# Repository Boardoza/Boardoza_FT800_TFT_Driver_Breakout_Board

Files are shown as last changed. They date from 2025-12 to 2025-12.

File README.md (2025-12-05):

# Boardoza FT800 TFT Driver Breakout Board

The **Boardoza FT800 TFT Driver Breakout Board** is a powerful graphics controller solution designed to simplify the creation of high-quality Human-Machine Interfaces (HMIs) for makers and embedded developers. Powered by the **Bridgetek (FTDI) FT800 Embedded Video Engine (EVE)**, this module unburdens your main microcontroller by handling complex graphics rendering, audio processing, and touch control on a dedicated chip. It is the perfect bridge for connecting low-cost MCUs to sophisticated color displays.

Operating with a **5V supply**, the board communicates via a standard **SPI interface** at speeds up to 30 MHz, making it compatible with popular platforms including Arduino, ESP32, STM32, and Raspberry Pi. It supports **WQVGA (480x272)** and **QVGA (320x240)** resolution TFT displays through a standard 40-pin FPC connector. Beyond graphics, it includes a built-in audio engine with PWM output for direct speaker connection. The FT800 offers flexible touch input options with **integrated resistive touch support** and **native capacitive touch connectivity via I²C**, providing a complete multimedia solution for industrial control panels, medical devices, IoT projects, and smart home interfaces.

## [Click here to purchase!](https://www.ozdisan.com/p/arduino-sensorleri-ve-modulleri-613/boardoza-boardoza-ft800-1473939)

|Front Side|Back Side|
|:---:|:---:|
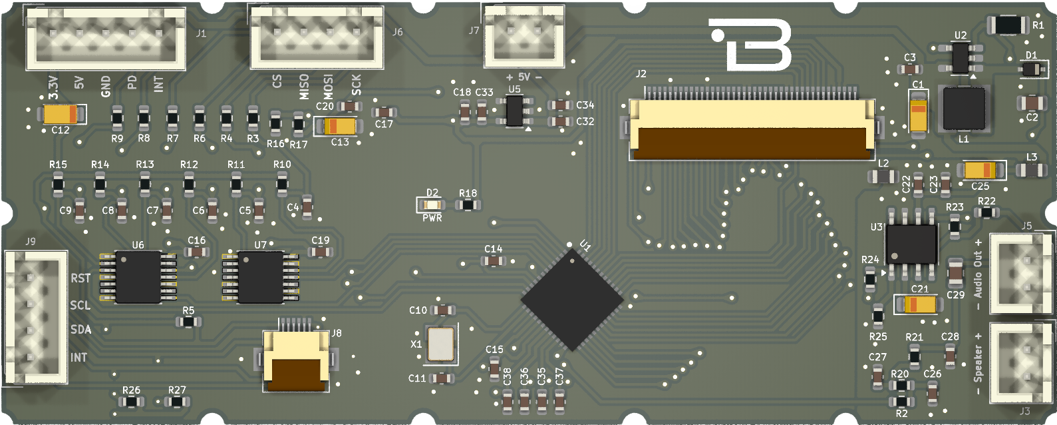
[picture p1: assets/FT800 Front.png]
FT800 Front
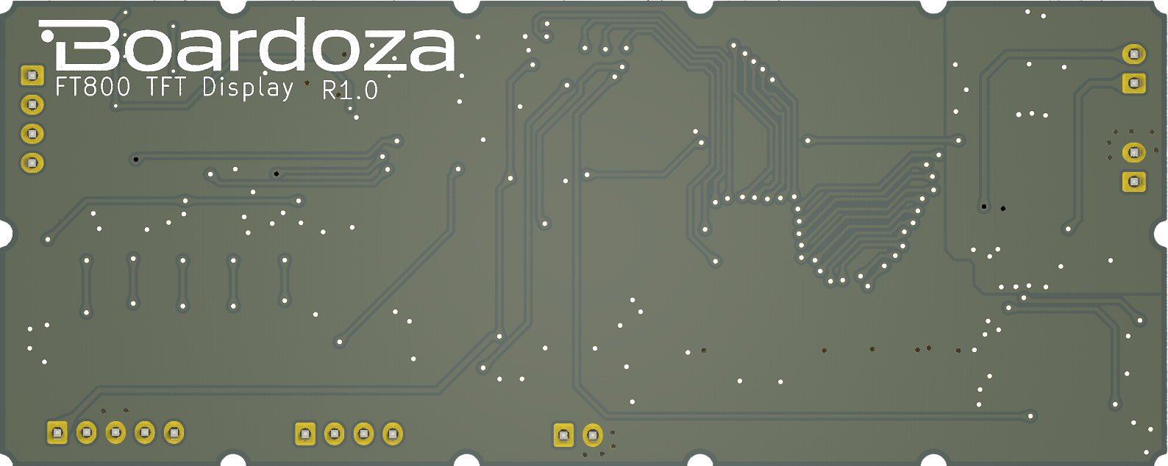
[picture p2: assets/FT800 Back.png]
FT800 Back
| | |

---

## Key Features

- **Dual Resolution Support:** Compatible with WQVGA (480x272) and QVGA (320x240) TFT panels with both DE mode and VSYNC/HSYNC synchronization.  
- **Works with any MCU:** Uses standard SPI, compatible with Arduino, ESP32, STM32, Raspberry Pi Pico, and more.  
- **Resistive & Capacitive Touch Support:** Integrated resistive and capacitive touch controller support via I²C.  
- **Audio Output:** Mono audio channel with PWM output and dedicated speaker connections.  
- **Object-Oriented Architecture:** Advanced command-based system enables low-cost host MCUs to create sophisticated HMI applications.  
- **Perfect for custom HMIs:** Great for dashboards, robotics screens, measurement devices, smart panels, and DIY UI projects.  
- **Display Control Signals:** Built-in display enable, pixel clock, and sync signal outputs for direct TFT panel control.  
- **Interrupt Capability:** Hardware interrupt output for efficient event-driven programming.  

---

## FT800 vs [FT810](https://github.com/Boardoza/Boardoza_FT810_TFT_Driver_Breakout_Board) Comparison

| Feature | FT800 | [FT810](https://github.com/Boardoza/Boardoza_FT810_TFT_Driver_Breakout_Board) |
|:---|:---:|:---:|
| **Supported Resolutions** | WQVGA (480x272), QVGA (320x240) | up to SVGA (800x600) |
| **Maximum Resolution** | WQVGA (480x272) | SVGA (800x600) |
| **Resistive Touch Support** | ✓ Integrated | ✓ Integrated |
| **Capacitive Touch Support** | ✓ Direct connection via I²C (J9) | ✗ Requires expansion board |
| **Audio Output** | ✓ Mono with PWM output, integrated speaker & line out | ✓ Mono with PWM output, integrated speaker & line out |
| **SPI Interface** | ✓ Up to 30 MHz | ✓ Up to 30 MHz |
| **Board Dimensions** | 40mm x 100mm | 40mm x 100mm |

> **Note:** The FT800 provides native capacitive touch support through the dedicated I²C connector (J9), allowing direct connection to capacitive touch panels. The FT810 focuses on resistive touch integration but can support capacitive touch through an external interface board if needed.

---

## Technical Specifications

**Model:** FT800  
**Manufacturer:** Bridgetek (FTDI)  
**Input Voltage:** 5V  
**Voltage Input Type:** Multiple pin connector (standard 2.50mm pitch)  
**Working Current:** 150mA  
**Functions:** Embedded Video Engine (Graphics Controller, Audio Processor, Touch Controller)  
**Interface:** SPI (up to 30 MHz), I²C (capacitive touch)  
**Supported Resolutions:** WQVGA (480x272), QVGA (320x240)  
**Display Modes:** Data Enable (DE), VSYNC/HSYNC  
**Touch Input:** Resistive (integrated), Capacitive (external via I²C)  
**Color Depth:** RGB666 (18-bit, 6-bit per color channel)  
**Audio Output:** Mono PWM audio channel  
**Connector Type:** 40-Pin FPC  
**Operating Temperature:** -40°C ~ +85°C  
**Board Dimensions:** 40mm x 100mm

---

## Board Pinout

### **( J1 ) Power and Control**

| Pin Number | Pin Name | Description |
|:---:|:---:|---|
| 1 | 3V3 | 3.3V Voltage Output |
| 2 | 5V | Board Supply Input |
| 3 | GND | Ground |
| 4 | PD | Power Down / Board Enable (Active High, 3.3V-5V compatible) |
| 5 | INT | Interrupt Output (3.3V logic level) |

### **( J2 ) TFT Display & Touch Interface**

| Pin Number | Pin Name | Description |
|:---:|:---:|---|
| 1 | LED- | LED Backlight Driver Negative |
| 2 | LED+ | LED Backlight Driver Positive |
| 3 | GND | Ground |
| 4 | VDD | 3.3V Power Output |
| 5 | GND | Ground |
| 6 | GND | Ground |
| 7 | R2 | Red RGB Signal Bit 2 |
| 8 | R3 | Red RGB Signal Bit 3 |
| 9 | R4 | Red RGB Signal Bit 4 |
| 10 | R5 | Red RGB Signal Bit 5 |
| 11 | R6 | Red RGB Signal Bit 6 |
| 12 | R7 | Red RGB Signal Bit 7 |
| 13 | GND | Ground |
| 14 | GND | Ground |
| 15 | G2 | Green RGB Signal Bit 2 |
| 16 | G3 | Green RGB Signal Bit 3 |
| 17 | G4 | Green RGB Signal Bit 4 |
| 18 | G5 | Green RGB Signal Bit 5 |
| 19 | G6 | Green RGB Signal Bit 6 |
| 20 | G7 | Green RGB Signal Bit 7 |
| 21 | GND | Ground |
| 22 | GND | Ground |
| 23 | B2 | Blue RGB Signal Bit 2 |
| 24 | B3 | Blue RGB Signal Bit 3 |
| 25 | B4 | Blue RGB Signal Bit 4 |
| 26 | B5 | Blue RGB Signal Bit 5 |
| 27 | B6 | Blue RGB Signal Bit 6 |
| 28 | B7 | Blue RGB Signal Bit 7 |
| 29 | GND | Ground |
| 30 | DATA_CLOCK | TFT Pixel Clock Output (Push-Pull) |
| 31 | DISP | Display Enable Output (Push-Pull) |
| 32 | HSYNC | Horizontal Sync Output (Push-Pull) |
| 33 | VSYNC | Vertical Sync Output (Push-Pull) |
| 34 | DE | Data Enable Output (Push-Pull) |
| 35 | NC | Not Connected |
| 36 | GND | Ground |
| 37 | X+ | Touch Screen Right Electrode |
| 38 | Y- | Touch Screen Bottom Electrode |
| 39 | X- | Touch Screen Left Electrode |
| 40 | Y+ | Touch Screen Top Electrode |

### **( J3 ) Speaker Output**

| Pin Number | Pin Name | Description |
|:---:|:---:|---|
| 1 | Speaker+ | Speaker Output Positive |
| 2 | Speaker- | Speaker Output Negative |

### **( J5 ) Audio Line Output**

| Pin Number | Pin Name | Description |
|:---:|:---:|---|
| 1 | Audio Out+ | Audio Line Output Positive |
| 2 | Audio Out- | Audio Line Output Negative |

### **( J6 ) SPI Communication**

| Pin Number | Pin Name | Description |
|:---:|:---:|---|
| 1 | CS | SPI Chip Select (Active Low) |
| 2 | MISO | SPI Master In, Slave Out |
| 3 | MOSI | SPI Master Out, Slave In |
| 4 | SCK | SPI Clock Input |

### **( J7 ) Auxiliary Power**

| Pin Number | Pin Name | Description |
|:---:|:---:|---|
| 1 | 5V+ | Board Supply Input |
| 2 | 5V- | Ground |

### **( J9 ) Capacitive Touch I²C Interface**

| Pin Number | Pin Name | Description |
|:---:|:---:|---|
| 1 | INT | Capacitive Touch Interrupt (Active Low) |
| 2 | SDA | I²C Serial Data Pin |
| 3 | SCL | I²C Serial Clock Pin |
| 4 | RST | Capacitive Touch Reset (Active Low) |

> **Note:** The FT800 includes an integrated resistive touch controller. The J9 connector provides optional support for external capacitive touch controllers via I²C interface.

---

## Board Dimensions

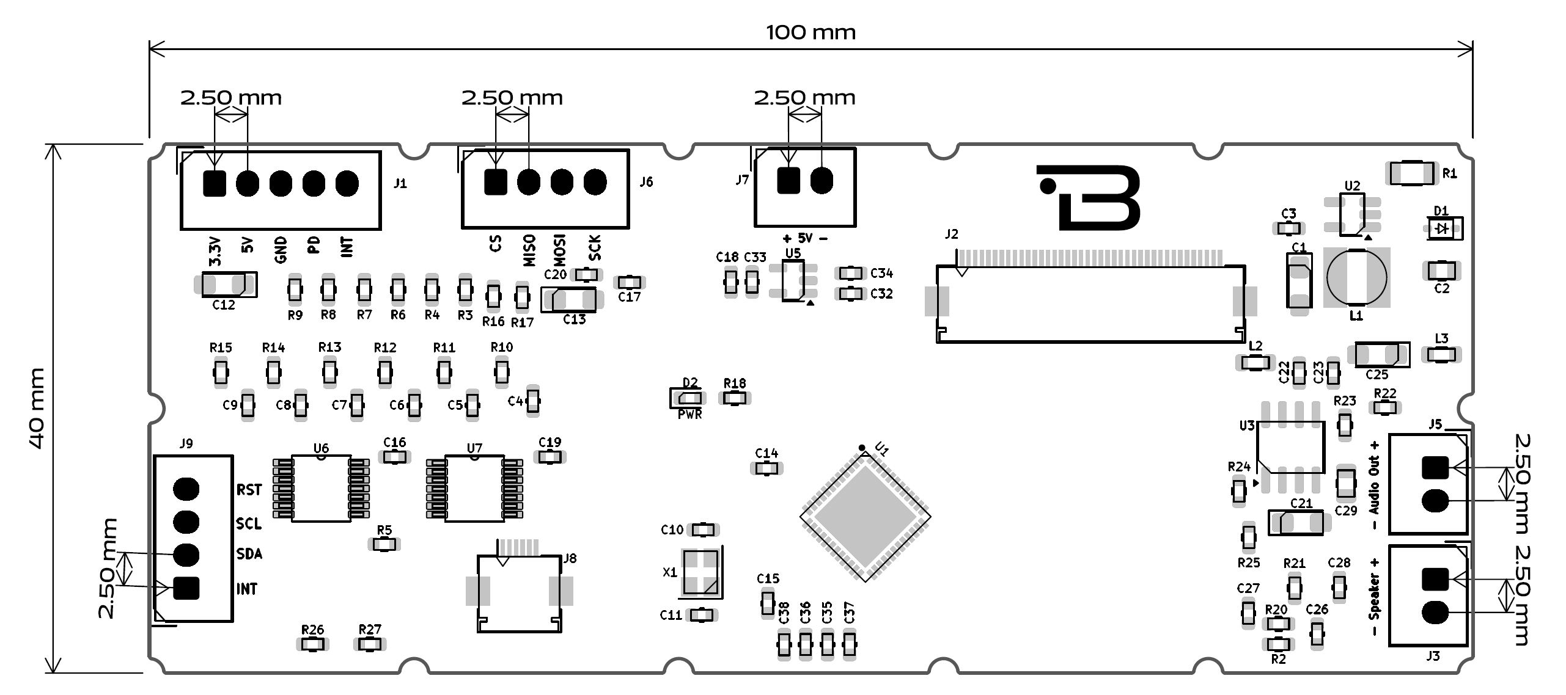
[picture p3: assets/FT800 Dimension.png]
FT800 Board Dimensions


---

## Step Files

[Boardoza FT800.step](./assets/FT800%20Step.step)

---

## Datasheet

[FTDI FT800 Datasheet.pdf](./assets/FT800%20Datasheet.pdf)

---

## Version History

- V1.0.0 – Initial Release  

---

## Support

For technical questions or assistance, please contact **<support@boardoza.com>**

---

## License

Shield: [][cc-by-sa]

This work is licensed under a [Creative Commons Attribution-ShareAlike 4.0 International License][cc-by-sa].

[][cc-by-sa]

[cc-by-sa]: http://creativecommons.org/licenses/by-sa/4.0/
[cc-by-sa-image]: https://licensebuttons.net/l/by-sa/4.0/88x31.png
[cc-by-sa-shield]: https://img.shields.io/badge/License-CC%20BY--SA%204.0-lightgrey.svg

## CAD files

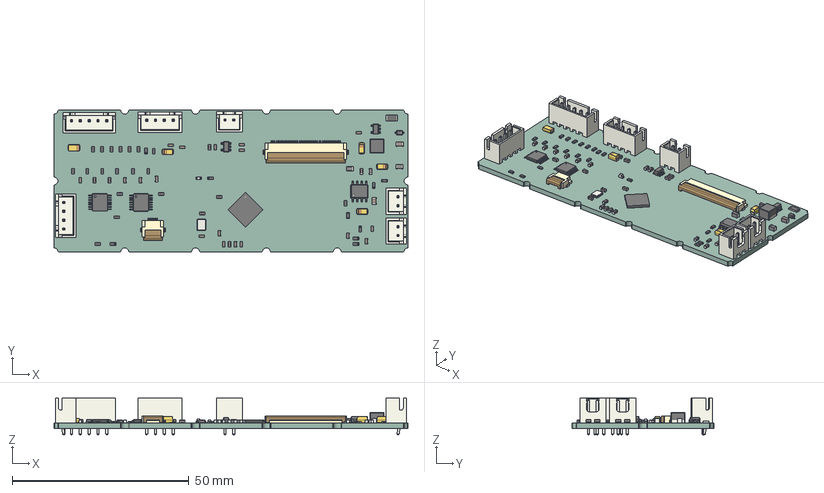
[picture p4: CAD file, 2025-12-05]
assets/FT800 Step.step
100.0 x 40.0 x 10.4 mm
R_0603_1608Metric x 25
L_Cenker_CKCS4030
C_0603_1608Metric x 28
Texas_RGZ0048A_VQFN-48-1EP_7x7mm_P0.5mm_EP5.15x5.15mm
C_0805_2012Metric x 2
LED_0603_1608Metric
CP_EIA_3216_18_Kemet_A x 4
JST_B5B_XH_A
TSSOP_14_44x5mm_P065mm x 2
SOT_23_5 x 2
SOIC_8_39x49mm_P127mm
D_SOD_323
L_0805_2012Metric x 2
Hirose_FH12_xxS_0_5SH_Parametric_v0_1 x 2
JST_B2B_XH_A x 3
R_1206_3216Metric
Crystal_SMD_3225-4Pin_3.2x2.5mm
JST_B4B_XH_A x 2
CP_EIA_3216_10_Kemet_I
_autosave-B-FT800-BRK_PCB

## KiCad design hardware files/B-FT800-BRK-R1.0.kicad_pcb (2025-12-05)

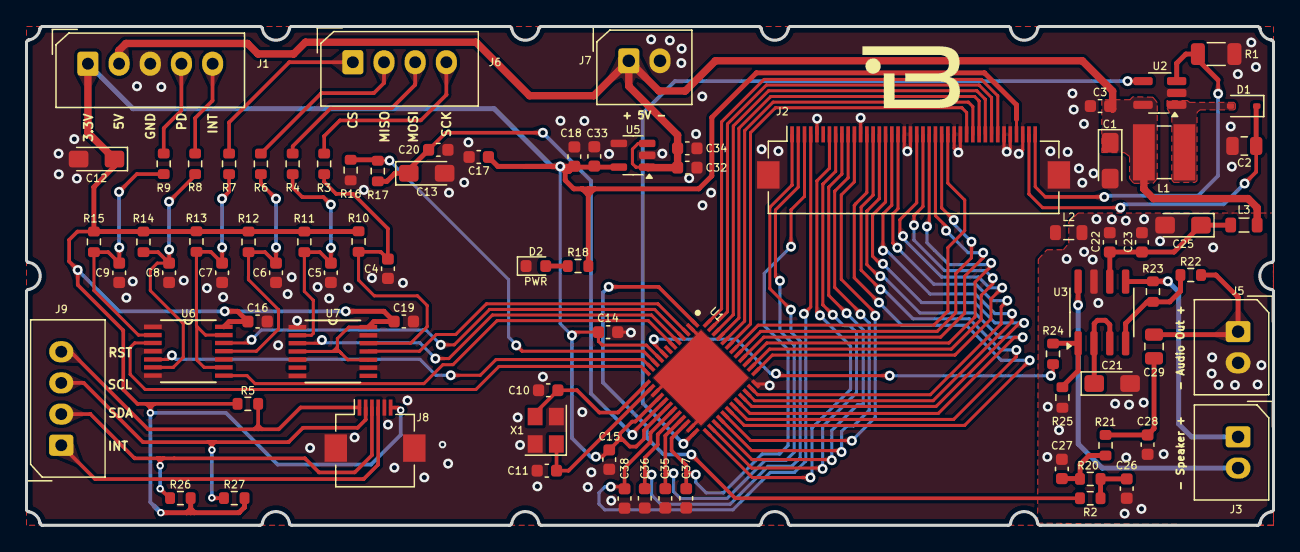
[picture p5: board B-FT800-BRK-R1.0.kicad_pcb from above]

Board: 2 copper layers, 100.0 x 40.0 mm, 81 parts (0 on the bottom side), 74 nets.

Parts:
C1: 1uF 35V A tantal; CP_EIA-3216-18_Kemet-A_Pad1.58x1.35mm_HandSolder
C2: 220nF; C_0805_2012Metric
C3, C14, C15, C16, C17, C18, C19, C20, C23, C34: 100nF; C_0603_1608Metric
C4, C5, C6, C7, C8, C9: 10pF; C_0603_1608Metric
C10, C11: 27pF; C_0603_1608Metric
C12, C13, C21, C25: 4,7uF 10V A tantal; CP_EIA-3216-18_Kemet-A_Pad1.58x1.35mm_HandSolder
C22: 10nF; C_0603_1608Metric
C26, C27, C28: 4,7nF; C_0603_1608Metric
C29: 330nF; C_0805_2012Metric
C32, C33: 1uF; C_0603_1608Metric
C35, C36, C37, C38: 3,3nF; C_0603_1608Metric
D1: SS0840WS_R1_00001; D_SOD-323
D2: RED; LED_0603_1608Metric
J1: Conn_01x05; 2317-05S_1x05_P2.50mm_Vertical
J2: Conn_01x40; Hirose_FH12-40S-0.5SH_1x40-1MP_P0.50mm_Horizontal
J3, J5, J7: Conn_01x02; 2317-02S_1x02_P2.50mm_Vertical
J6, J9: Conn_01x04; 2317-04S_1x04_P2.50mm_Vertical
J8: Conn_01x06; Hirose_FH12-6S-0.5SH_1x06-1MP_P0.50mm_Horizontal
L1: PCD0403MT100; L_Ferrocore_DLG-0403
L2, L3: LCB2012-601Y-N; L_0805_2012Metric
R1: 2R2; R_1206_3216Metric
R2, R20, R21: 1K; R_0603_1608Metric
R3, R4, R6, R7, R8, R9, R24: 33R; R_0603_1608Metric
R5, R22, R26, R27: 10K; R_0603_1608Metric
R10, R11, R12, R13, R14, R15, R16, R25: 47K; R_0603_1608Metric
R17: NC; R_0603_1608Metric
R18: 330R; R_0603_1608Metric
R23: 20K; R_0603_1608Metric
U1: FT800Q-R; QFN50P700X700X100-49N-D
U2: MIC2287CYD5-TR; SOT-23-5_HandSoldering
U3: AP4890; SOIC-8_3.9x4.9mm_P1.27mm
U5: TLV70033DDCR; SOT-23-5
U6, U7: MC74LCX125DTR2G; SOP65P640X120-14N
X1: RH100-12.000-18-2020-TR; Crystal_SMD_3225-4Pin_3.2x2.5mm

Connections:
/Connectors/AGND: C21.2, C22.1, C23.1, C25.2, C26.2, C27.1, C28.1, J5.2, L2.1, R25.1, U3.7 (GND)
/Connectors/INTC: J8.3, J9.1
/Connectors/RST: J8.6, J9.4, R5.1
/Connectors/SCL: J8.5, J9.3, R27.1
/Connectors/SDA: J8.4, J9.2, R26.1
/LED_OUT: D1.2 (A), L1.2, U2.1 (VOUT)
AUDIO: R2.2, U1.1 (AUDIO_L)
AUDIO_SHDN: R24.1, U1.8 (GPIO1)
B2: J2.23, U1.35 (B2)
B3: J2.24, U1.34 (B3)
B4: J2.25, U1.33 (B4)
B5: J2.26, U1.32 (B5)
B6: J2.27, U1.31 (B6)
B7: J2.28, U1.30 (B7)
BLIGHT: U1.24 (BACKLIGHT), U2.4 (EN)
CS: C7.2, R7.1, R13.2, U6.9 (A3), U6.13 (~OE2)
DATA_CLOCK: J2.30, U1.29 (PCLK)
DE: J2.34, U1.25 (DE)
DISP: J2.31, U1.28 (DISP)
FT_CS: U1.6 (CS_N/_I2C_SA1), U6.8 (O3)
FT_INT: U1.11 (INT_N), U6.5 (A1)
FT_MISO: U1.4 (MISO/_I2C_SDA), U6.12 (A2)
FT_MOSI: U1.5 (MOSI/_I2C_SA0), U7.3 (O0)
FT_PD: U1.12 (PD_N), U6.3 (O0)
FT_SCK: U1.3 (SPI_SCLK/_I2C_SCL), U7.11 (O2)
G2: J2.15, U1.42 (G2)
G3: J2.16, U1.41 (G3)
G4: J2.17, U1.40 (G4)
G5: J2.18, U1.39 (G5)
G6: J2.19, U1.38 (G6)
G7: J2.20, U1.37 (G7)
GND: C1.2, C2.2, C3.1, C4.1, C5.1, C6.1, C7.1, C8.1, C9.1, C10.1, C11.2, C12.2, C13.2, C14.2, C15.2, C16.2, C17.2, C18.2, C19.2, C20.2, C32.2, C33.2, C34.2, C35.1, C36.2, C37.1, C38.1, D2.1 (K), J1.3, J2.3, J2.5, J2.6, J2.13, J2.14, J2.21, J2.22, J2.29, J2.36, J2.41, J2.42, J7.2, J8.2, J8.MP, L2.2, R1.1, R16.2, U1.2 (GND_1), U1.15 (GND_2), U1.23 (GND_3), U1.36 (GND_4), U1.49 (GND_5), U2.2 (GND), U5.2 (GND), U5.4 (BP), U6.1 (~OE0), U6.4 (~OE1), U6.7 (GND), U6.10 (~OE3), U7.1 (~OE0), U7.5 (A1), U7.7 (GND), U7.9 (A3), U7.13 (~OE2), X1.2, X1.4
HSYNC: J2.32, U1.27 (HSYNC)
INT: C8.2, R8.1, R14.2, U6.6 (O1)
LED+: C2.1, D1.1 (K), J2.2
LED-: J2.1, R1.2, U2.3 (FB)
MISO: C6.2, R6.1, R12.1, U6.11 (O2)
MOSI: C5.2, R4.1, R11.1, U7.2 (A0)
unnamed: C26.1, R2.1, R20.2
unnamed: C27.2, R20.1, R21.2
unnamed: C28.2, C29.1, R21.1
unnamed: D2.2 (A), R18.1
unnamed: J1.4, R9.2
unnamed: J1.5, R8.2
unnamed: J3.1, R23.1, U3.5 (OUT+)
unnamed: J3.2, U3.8 (OUT-)
unnamed: C29.2, J5.1, R22.1
unnamed: J6.1, R7.2
unnamed: J6.2, R6.2
unnamed: J6.3, R4.2
unnamed: J6.4, R3.2
unnamed: R16.1, R17.2, U1.10 (MODE)
unnamed: C21.1, U3.2 (BYPASS), U3.3 (IN+)
unnamed: R22.2, R23.2, U3.4 (IN-)
unnamed: C22.2, C23.2, C25.1, L3.1, U3.6 (VDD)
unnamed: R24.2, R25.2, U3.1 (~SD)
OSC_IN: C10.2, U1.13 (X1/_CLK), X1.3
OSC_OUT: C11.1, U1.14 (X2), X1.1
PD: C9.2, R9.1, R15.2, U6.2 (A0)
R2: J2.7, U1.48 (R2)
R3: J2.8, U1.47 (R3)
R4: J2.9, U1.46 (R4)
R5: J2.10, U1.45 (R5)
R6: J2.11, U1.44 (R6)
R7: J2.12, U1.43 (R7)
SCK: C4.2, R3.1, R10.1, U7.12 (A2)
VDD: C12.1, C14.1, C15.1, C16.1, C17.1, C18.1, C19.1, C33.1, J1.1, J2.4, J8.1, R5.2, R10.2, R11.2, R12.2, R13.1, R14.1, R15.1, R18.2, R26.2, R27.2, U1.9 (VCCIO), U1.16 (VCC_1), U1.18 (VCC_2), U5.5 (OUT), U6.14 (VCC), U7.4 (~OE1), U7.10 (~OE3), U7.14 (VCC)
VDD_BL: C1.1, C3.2, C32.1, C34.1, J1.2, J7.1, L1.1, L3.2, U2.5 (VBAT), U5.1 (IN), U5.3 (EN)
VDD_Core: C13.1, C20.1, R17.1, U1.17 (VCC1V2)
VSYNC: J2.33, U1.26 (VSYNC)
X+: C38.2, J2.37, U1.19 (X+)
X-: C35.2, J2.39, U1.21 (X-)
Y+: C36.1, J2.40, U1.20 (Y+)
Y-: C37.2, J2.38, U1.22 (Y-)
